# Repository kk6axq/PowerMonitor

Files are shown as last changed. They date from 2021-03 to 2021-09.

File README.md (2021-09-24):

# Power Monitor
This is a power management board for small robotics applications. This project was
developed as part of an honors contract for EGR216, electrical fundamentals,
during my Spring 2021 semester at Arizona State University, under the guidance
of Dr. Ayan Mallik.

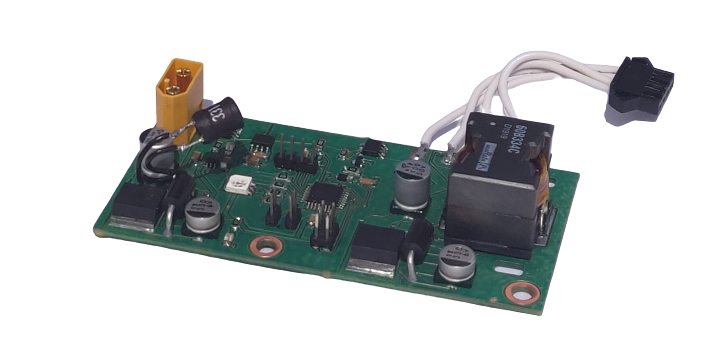
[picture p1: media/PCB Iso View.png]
PCB Photo


# Purpose
The purpose of this project was to interface with a LiPo battery for a robotics
project I am developing in another course. The purpose of the board was to
prevent issues stemming from over discharge of the battery or accidental shorting.
As LiPo batteries are capable of delivering a large amount of current,
I wanted to prevent circuit damage in the case of short circuit conditions while
also preventing battery damage if I forgot to turn off the robot.
Additionally, I wanted to explore an alternative to the LM7805 I had used in
previous projects to provide a high current 5V supply for a planned payload bay
on the robot.
# Features
* Variety of current protection features:
  * Overcurrent up to 10A
  * Overvoltage detection up to 25V
  * Undervoltage detection
  * Short circuit protection
* Independent load control. Load, and 5V load supply can be switched on or off by the onboard microcontroller.
* Provides 5V at up to 3A and 12V at up to 10A burst.
* Dual power supplies for load and onboard microcontroller.
* Serial based monitoring and control of load switch, power status, and fault conditions.
* Onboard RGB LED for status indication
* Open source software.
* Hardware schematic and layout is open source. Project files are currently not available due to licensing restrictions.
# Design Criteria
* 12V power source or 3s LiPo battery
* Provide 12V at 4.2A from battery and 5V at 1.5A
* Monitor for fault conditions, including overvoltage, undervoltage, overcurrent, and short circuit
* Report faults to the robot's main microcontroller

# Core components:
* ATTiny88 microcontroller programmed with Arduino and the ATTinyCore
* ACS722 Current Sensor with +/- 10A current measuring capacity
* Voltage divider based voltage sensor with 25V measuring capability
* Dual LM2576 5V buck converter
* MIC5504 3.3V regulator for current sensor
* Si4435 P-Channel MOSFET for short circuit protection and load switching
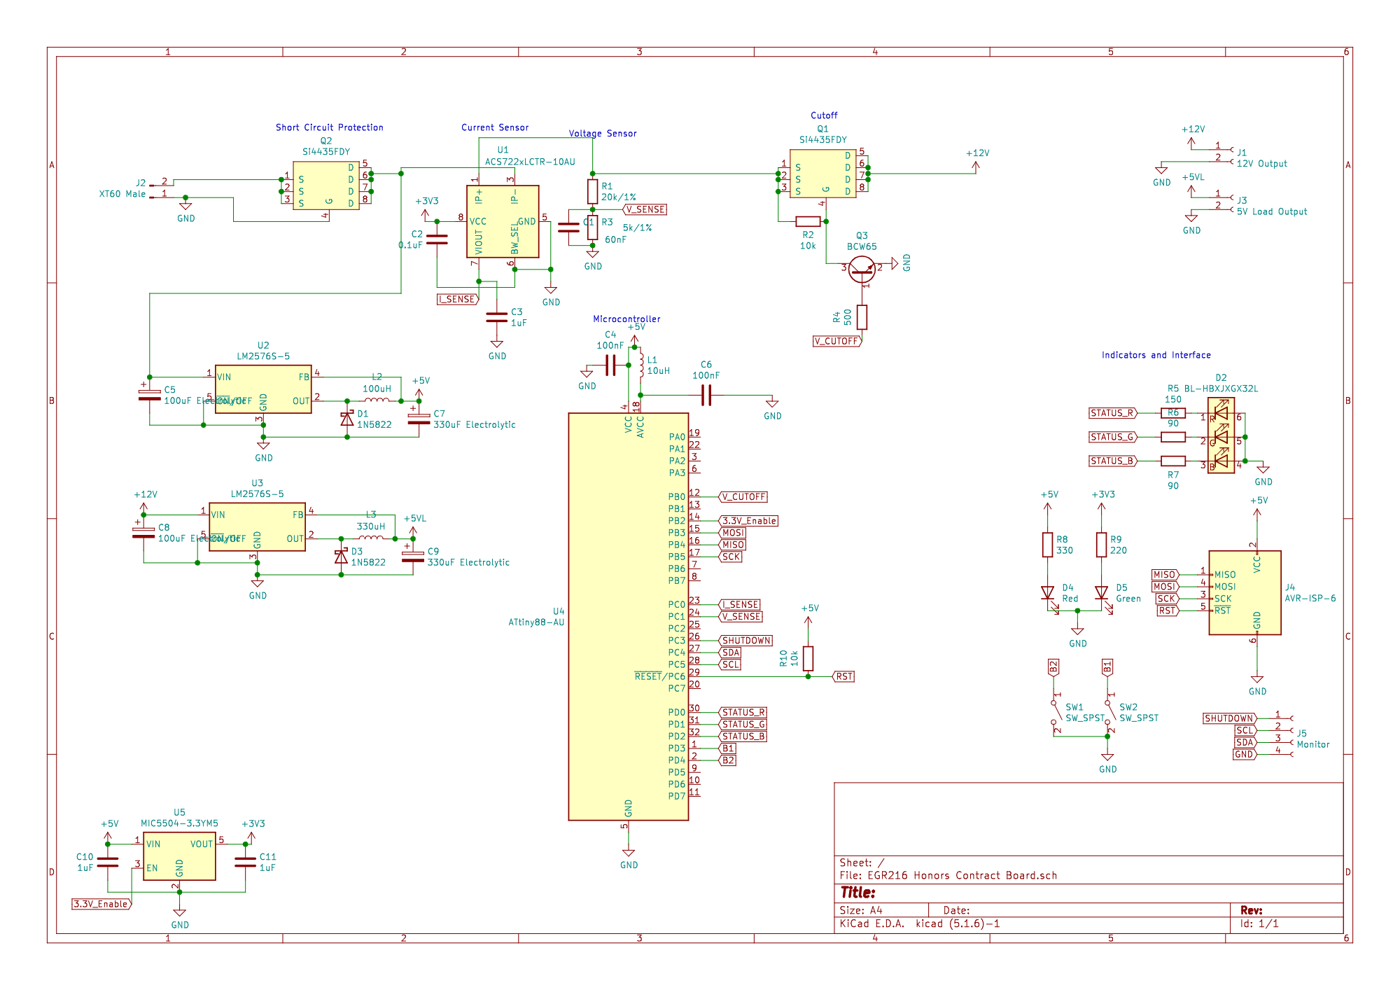
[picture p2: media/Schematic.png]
Schematic

# Repository Structure:
The repository is organized by folder, as shown below.
## Hardware
The hardware folder contains the KiCAD project files and output Gerbers and PDFs
for easy viewing. It includes:
* PDF schematic
* STEP file of PCB
* Bill of Materials
* Interactive HTML BOM for PCB assembly
* KiCAD project files
* Archive of Gerber board files and PDF of PCB layers

## Software
The software folder contains the code used to enable the power management behaviors.
## Docs
The docs folder contains documentation of the digital communications protocol and an explanation of the operation of the device.

# License
This project is copyright (C) 2021 by Lukas Severinghaus. It is licensed under the GNU GPLV3.

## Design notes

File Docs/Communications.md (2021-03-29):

# Digital Communications Protocol
The board communicates over a 9600 baud UART connection provided through the
onboard payload connector. The connector itself is a 4 pin 2.54mm pitch male
connector that can easily be interfaced with jumper wires or a 2.54mm pitch
wiring harness. This UART runs on a 5V logic level, though it should be capable
of receiving 3.3V logic level signals.

## Purpose
The purpose of the protocol is to provide an interface for the host device to
monitor the power status, and to provide human readable debugging output and
control.
## Protocol basics
There are two packet structures in the protocol. All packets start with either
`$` or `&` and end with a `;` character, all in ASCII. Packets starting with a
`&` are human readable debug messages, and are sent on major state changes.
Messages starting with `$` are human readable debug messages, and are currently
only sent on request. Commands can be sent to the device by sending a single
character.

## Commands
The following single character commands are recognized. All others, including
newline characters, are ignored.
* `m`: Enter command mode. The device will begin accepting
character commands/
* `x`: Exist command mode. The device will stop accepting character commands.
* `r`: Reset the current fault. Resets the state machine to the no fault state, though it may go immediately back into a fault state if the fault conditions persist.
* `d`: Print debug packet. Prints the debug response, detailed below.
* `o`: Turn on load. Sets the load cutoff switch to allow current to flow into the load.
* `l`: Turn off load. Sets the load cutoff switch to prevent current from flowing into the load.

## Debug response
The only machine readable response currently given is the debug command. This is
sent when the `d` character is sent to the device. The current response is in
the form:

  `$ Power_State Current Voltage Fault_State;`

`Power_State` is the current state of the load switch, `1` for load on,
and `0` for load off. `Current` is the measured load current in Amps. `Voltage`
is the measured supply voltage, in Volts. `Fault_State` is a flag for the current
state of the protection state machine. It has the following response codes:
* `c`: State clear. Everything is fine.
* `t`: An initial fault has been observed and the device is waiting to see if
the condition persists beyond the timeout limit.
* `s`: A soft trip fault has been encountered. The system has experienced a
recoverable fault and will periodically check to see if the fault has been
resolved. As of now the two soft trip conditions are overcurrent and overvoltage.
* `h`: A hard trip fault has been encountered. Ths system experienced an
unrecoverable fault and must be manually reset either by power cycling the
device or sending the `r` reset command. As of now, the only hard trip condition
is under voltage.
* `u`: Unknown condition. This should never be received in normal operation. If
it is, the device should be reset as there has been a fault in the code.

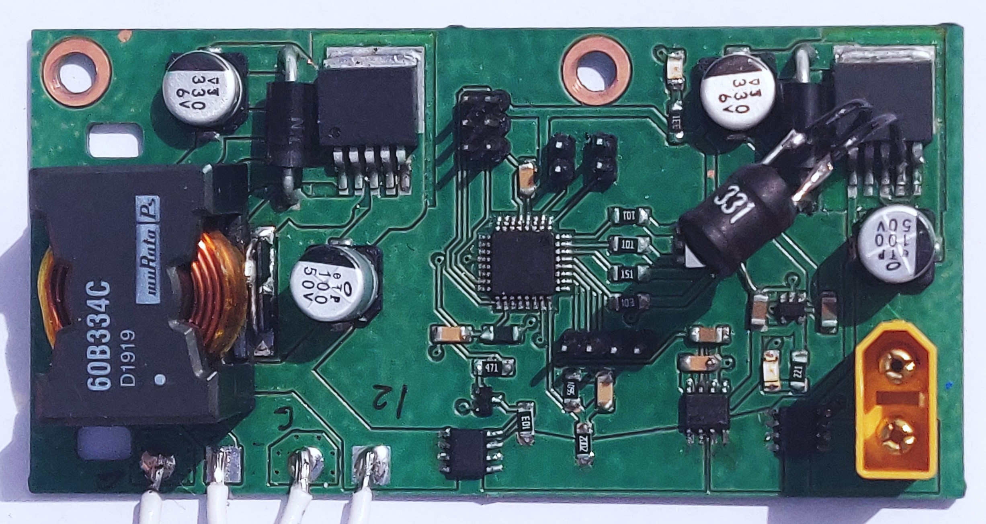
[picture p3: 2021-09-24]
media/PCB Front.jpg

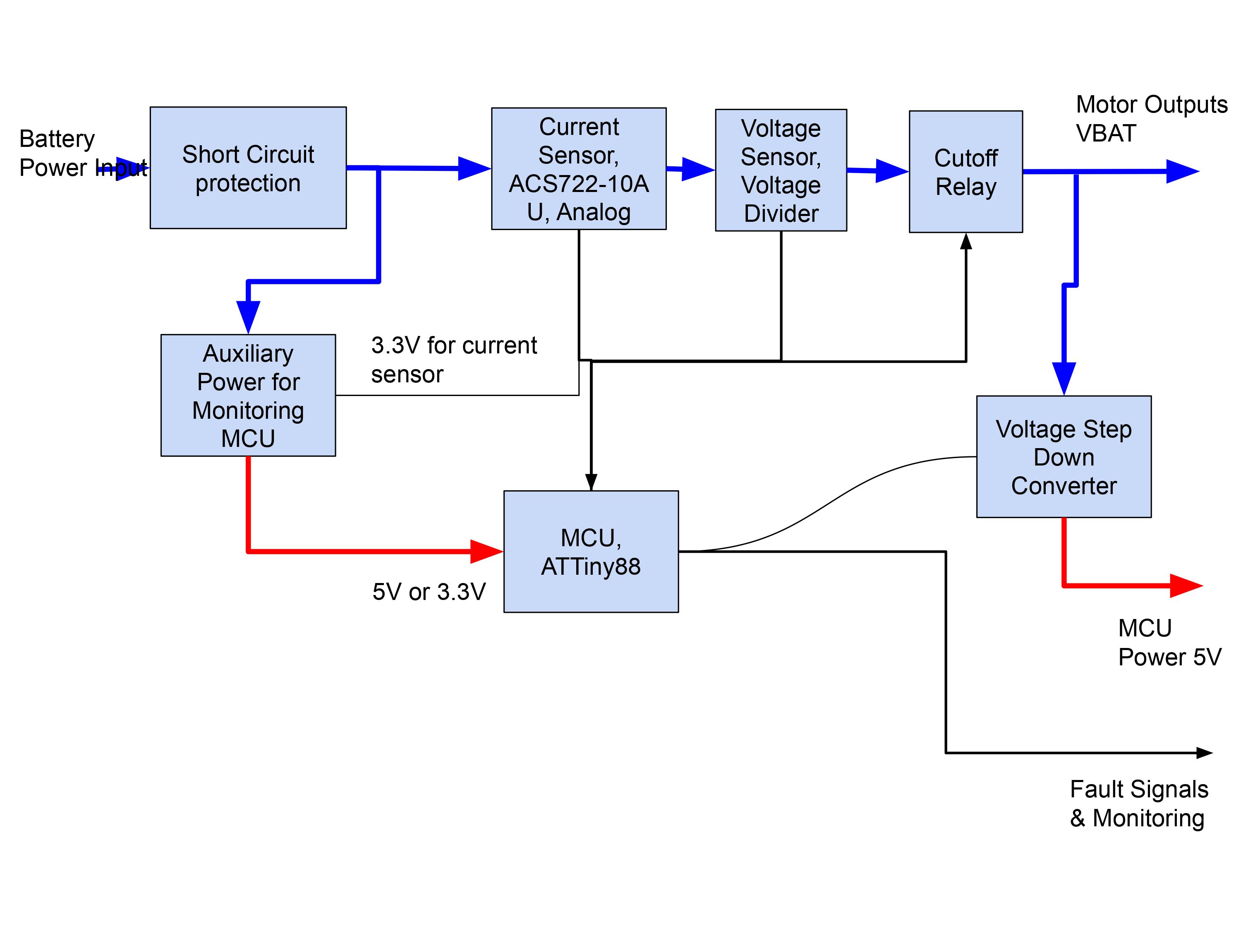
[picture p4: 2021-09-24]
media/Block Diagram.jpg

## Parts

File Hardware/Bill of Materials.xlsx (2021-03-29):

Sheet: Through Hole BOM
Universal Reference | Board Reference | Qty | Actual Qty | Value | Footprint | Part number | Price | Note |  | One board price |  | Total purchase price
Power THT C1 | C1 | 1 | 10 | 60nF | THT | 399-14063-ND | $0.26 |  |  | $0.26 |  | $2.59
Power THT C11 C10 C3 | C11 C10 C3 | 3 | 15 | 1uF | THT | 445-8395-ND | $0.22 |  |  | $0.66 |  | $3.30
Power THT C2 | C2 | 1 | 10 | 0.1uF | THT | 399-4151-ND | $0.16 |  |  | $0.16 |  | $1.57
Power THT C5 C8 | C5 C8 | 2 | 10 | 100uF Electrolytic | THT | 1572-1659-ND | $0.13 |  |  | $0.25 |  | $1.26
Power THT C6 C4 | C6 C4 | 2 | 10 | 100nF | THT | 399-4151-ND | $0.16 |  |  | $0.31 |  | $1.57
Power THT C7 C9 | C7 C9 | 2 | 10 | 330uF Electrolytic | THT | 1572-1437-ND | $0.21 |  |  | $0.43 |  | $2.15
Power THT D1 D3 | D1 D3 | 2 |  | 1N5822 | THT | 497-11370-1-ND | $0.28 |  |  | $0.56 |  | $0.00
Power THT D2 | D2 | 1 | 1 | BL-HBXJXGX32L | 5050 | BL-HBXJXGX32LCT-ND | $0.40 | Use SMD |  | $0.40 |  | $0.40
Power THT D4 | D4 | 1 | 10 |  |  |  |  | Already Have |  | $0.00 |  | $0.00
Power THT D5 | D5 | 1 | 10 |  |  |  |  | Already Have |  | $0.00 |  | $0.00
Power THT J1 | J1 | 1 |  | 12V Output |  |  |  | Already Have |  | $0.00 |  | $0.00
Power THT J2 | J2 | 1 |  | XT60 Male | Amass:AMASS_XT60-M_1x02_P7.20mm_Vertical |  |  | Already Have |  | $0.00 |  | $0.00
Power THT J3 | J3 | 1 |  | 5V Load Output | Connector_PinHeader_2.54mm:PinHeader_1x02_P2.54mm_Vertical |  |  | Already Have |  | $0.00 |  | $0.00
Power THT J4 | J4 | 1 | 5 | AVR-ISP-6 | 2x3 2.54 |  |  | Already Have |  | $0.00 |  | $0.00
Power THT J5 | J5 | 1 |  | Monitor | 2.54 |  |  | Already Have |  | $0.00 |  | $0.00
Power THT L1 | L1 | 1 | 5 | 10uH | THT | 78F100J-TR-RCTR-ND | $0.25 |  |  | $0.25 |  | $1.26
Power THT L2 L3 | L2 L3 | 2 | 3 | 330uH | THT | 595-1734-ND | $2.54 |  |  | $5.08 |  | $7.62
Power THT Q2 Q1 | Q2 Q1 | 2 | 10 | Si4435FDY | SOIC8 | SI4435FDY-T1-GE3CT-ND | $0.38 | Use SMD |  | $0.76 |  | $3.82
Power THT Q3 | Q3 | 1 | 10 | BC856 | SOT23-3 | BC856BLT3GOSCT-ND | $0.09 | Use SMD |  | $0.09 |  | $0.88
Power THT R1 | R1 | 1 | 5 | 20k/1% | THT | RNF14FTD20K0TR-ND | $0.10 |  |  | $0.10 |  | $0.50
Power THT R10 R2 | R10 R2 | 2 | 20 | 10k |  |  |  | Already have |  | $0.00 |  | $0.00
Power THT R3 | R3 | 1 | 5 | 5k/1% | THT | 1135-1619-ND | $0.50 |  |  | $0.50 |  | $2.50
Power THT R4 | R4 | 1 | 10 | 500 | THT | CF14JT470RCT-ND | $0.04 | 470ohms |  | $0.04 |  | $0.36
Power THT R5 | R5 | 1 | 10 | 150 | THT | CF14JT150RCT-ND | $0.04 |  |  | $0.04 |  | $0.36
Power THT R6 R7 | R6 R7 | 2 | 10 | 90 | THT | CF14JT100RCT-ND | $0.04 | 100ohms |  | $0.07 |  | $0.36
Power THT R8 | R8 | 1 | 10 | 330 |  |  |  | Already Have |  | $0.00 |  | $0.00
Power THT R9 | R9 | 1 | 10 | 220 |  |  |  | Already Have |  | $0.00 |  | $0.00
Power THT SW2 SW1 | SW2 SW1 | 2 | 2 | SW_SPST |  |  |  | Already Have |  | $0.00 |  | $0.00
Power THT U1 | U1 | 1 | 1 | ACS722xLCTR-10AU | SOIC8 | 620-1636-1-ND | $3.94 | Use SMD |  | $3.94 |  | $3.94
Power THT U2 U3 | U2 U3 | 2 | 3 | LM2576S-5 | THT | 576-1518-5-ND | $2.01 |  |  | $4.02 |  | $6.03
Power THT U4 | U4 | 1 | 5 | ATtiny88-AU | THT | ATTINY88-PU-ND | $1.80 |  |  | $1.80 |  | $9.00
Power THT U5 | U5 | 1 | 10 | MIC5504-3.3YM5 | SOT-23-5 | 576-4764-1-ND | $0.13 | Use SMD |  | $0.13 |  | $1.30
 |  |  |  |  |  |  |  |  | Total | $19.85 | Total | $50.77

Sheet: SMD BOM
Universal Reference | Board Reference | Qty | Actual Qty | Value | Footprint | Part number | Price | Note |  | One board price |  | Actual price | Status: | Ready to order
Power C1 | C1 | 1 | 10 | 60nF | 1206 | 2368-SMC1206K563-ND | $0.12 |  |  | $0.12 |  | $1.24
Power C11 C10 C3 | C11 C10 C3 | 3 | 15 | 1uF | 1206 | 1276-1097-2-ND | $0.10 |  |  | $0.31 |  | $1.53
Power C2 | C2 | 1 |  | 0.1uF | 1206 | 2368-SMC1206Z104-ND | $0.05 |  |  | $0.05 |  | $0.00
Power C5 C8 | C5 C8 | 2 | 10 | 100uF Electrolytic | Axial | 2616-VUJ101M1HTR-1313STR-ND | $0.12 |  |  | $0.24 |  | $1.20
Power C6 C4 | C6 C4 | 2 | 10 | 100nF | 1206 | 2368-SMC1206Z104-ND | $0.05 |  |  | $0.10 |  | $0.48
Power C7 C9 | C7 C9 | 2 | 10 | 330uF Electrolytic | Axial | 493-2091-2-ND | $0.22 |  |  | $0.44 |  | $2.21
Power D1 D3 | D1 D3 | 2 |  | 1N5822 | Axial | 497-11370-1-ND | $0.28 |  |  | $0.56 |  | $0.00
Power D2 | D2 | 1 | 10 | BL-HBXJXGX32L | 5050 | BL-HBXJXGX32LCT-ND | $0.40 |  |  | $0.40 |  | $4.01
Power D4 | D4 | 1 | 10 | RED | 1206 | 160-1168-1-ND | $0.18 | Vf 2v |  | $0.18 |  | $1.76
Power D5 | D5 | 1 | 10 | GREEN | 1206 | 160-1169-2-ND | $0.17 | Vf 2.1v |  | $0.17 |  | $1.69
Power J1 | J1 | 1 |  | 12V Output |  |  |  | Already Have |  | $0.00 |  | $0.00
Power J2 | J2 | 1 |  | XT60 Male | Amass:AMASS_XT60-M_1x02_P7.20mm_Vertical |  |  | Already Have |  | $0.00 |  | $0.00
Power J3 | J3 | 1 |  | 5V Load Output | Connector_PinHeader_2.54mm:PinHeader_1x02_P2.54mm_Vertical |  |  | Already Have |  | $0.00 |  | $0.00
Power J4 | J4 | 1 | 5 | AVR-ISP-6 | 2x3 2.54 | 2057-PH2-06-UA-ND | $0.12 |  |  | $0.12 |  | $0.60
Power J5 | J5 | 1 |  | Monitor | Connector_PinHeader_2.54mm:PinHeader_1x04_P2.54mm_Vertical |  |  | Already Have |  | $0.00 |  | $0.00
Power L1 | L1 | 1 | 5 | 10uH | 1206 | 541-2607-2-ND | $0.23 | 25mA max |  | $0.23 |  | $1.15
Power L2 L3 | L2 L3 | 2 | 3 | 330uH | nonstandard | 811-2464-ND | $2.97 |  |  | $5.94 |  | $8.91
Power Q2 Q1 | Q2 Q1 | 2 | 10 | Si4435FDY | SOIC8 | SI4435FDY-T1-GE3CT-ND | $0.38 |  |  | $0.76 |  | $3.82
Power Q3 | Q3 | 1 | 10 | BC856 | SOT23-3 | BC856BLT3GOSCT-ND | $0.09 |  |  | $0.44 |  | $2.21
Power R1 | R1 | 1 | 10 | 20k/1% | 1206 | 311-20.0KFRCT-ND | $0.10 |  |  | $0.56 |  | $0.00
Power R10 R2 | R10 R2 | 2 | 20 | 10k | 1206 | RMCF1206JT10K0CT-ND | $0.03 | Already have |  | $0.40 |  | $4.01
Power R3 | R3 | 1 | 10 | 5k/1% | 1206 | A129819CT-ND | $0.10 |  |  | $0.18 |  | $1.76
Power R4 | R4 | 1 | 10 | 500 | 1206 | RMCF1206JT470RCT-ND | $0.03 | 470ohms |  | $0.17 |  | $1.69
Power R5 | R5 | 1 | 10 | 150 | 1206 | RMCF1206JT150RCT-ND | $0.03 |  |  | $0.00 |  | $0.00
Power R6 R7 | R6 R7 | 2 | 10 | 90 | 1206 | RMCF1206JT100RCT-ND | $0.03 | 100ohms |  | $0.00 |  | $0.00
Power R8 | R8 | 1 | 10 | 330 | 1206 | RMCF1206JT330RCT-ND | $0.03 |  |  | $0.00 |  | $0.00
Power R9 | R9 | 1 | 10 | 220 | 1206 | RMCF1206JT220RCT-ND | $0.03 |  |  | $0.12 |  | $0.60
Power SW2 SW1 | SW2 SW1 | 2 |  | SW_SPST |  |  |  | Already Have |  | $0.00 |  | $0.00
Power U1 | U1 | 1 | 5 | ACS722xLCTR-10AU | SOIC8 | 620-1636-1-ND | $3.94 |  |  | $0.23 |  | $1.15
Power U2 U3 | U2 U3 | 2 | 6 | LM2576S-5 | TO265-5 | LM2576S-5.0/NOPB-ND | $3.53 |  |  | $5.94 |  | $8.91
Power U4 | U4 | 1 | 5 | ATtiny88-AU | TQFP32 | ATTINY88-AU-ND | $1.04 |  |  | $0.76 |  | $3.82
Power U5 | U5 | 1 | 10 | MIC5504-3.3YM5 | SOT-23-5 | 576-4764-1-ND | $0.13 |  |  | $0.09 |  | $0.88
 |  |  |  |  |  |  |  |  | Total: | $18.51 | Total: | $53.63

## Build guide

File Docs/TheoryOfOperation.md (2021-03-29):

# Theory of Operation
The device functions on a fairly basic state machine. There are currently 3 fault conditions that are measured: overcurrent, undervoltage, and overvoltage.

For each of these, the applicable sensor is measured against a
threshold value and a corresponding flag is set. If the system
is currently in a clear state, meaning there are no existing faults, the system transitions into a time state, where it checks if the faults persist for more than the timeout threshold, 50ms. If the fault condition still persists, it decides, based on the type of fault, whether to enter a soft or hard fault.

A soft fault is a condition that is likely momentary, and can be recovered from. The two situations envisioned are momentary overcurrent spikes from the motors stalling or a brief high voltage spike from back EMF from the motors. In this case, the system disconnects the load but will reconnect it once per second to see if the condition has been resolved. Once it has, the system returns to the normal clear state.

A hard fault is a condition that is likely permanent, and needs human intervention to be resolved. The situation envisioned for this is a low voltage condition, where the battery needs to be replaced to prevent damage from undervoltage. In this case, the system disconnects the load and will wait for either a system reset, as in the case of a battery replacement, or a reset command from the host microcontroller. If neither of these are met, the system will perpetually stay in a load-disconnected hard fault state, otherwise, once the flag is reset by one of those two methods, the system will return to a normal fault clear state.

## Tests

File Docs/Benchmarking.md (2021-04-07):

# Benchmarking
To verify the functionality of the device, I performed static load testing using high wattage resistors to check voltage ripple under load. These tests were performed in Dr. Mallik's lab on April 7, 2021.

## 5V system
The 5V on board switching regulator was tested at three load conditions: no load, 1A load, and 2A load. The raw results of the test are shown below:

### Raw Testing Data
| Trial | Unit | 1 | 2 | 3 |
|---|---|---|---|---|
| Current | A | 0 | 1 | 2 |
| Expected V | V | 5 | 5 | 5 |
| RMS | Vrms | 4.85  | 4.796 | 4.795 |
| Max | V | 4.95  | 4.91  | 4.905 |
| Min | V | 4.78  | 4.71  | 4.7 |
| P-P Ripple | mV | 150 | 220 | 207 |
| Load | Ohm  | 0 | 5 | 2.5 |
| Ripple | % | 3.09% | 4.59% | 4.32% |

### Graphed Ripple
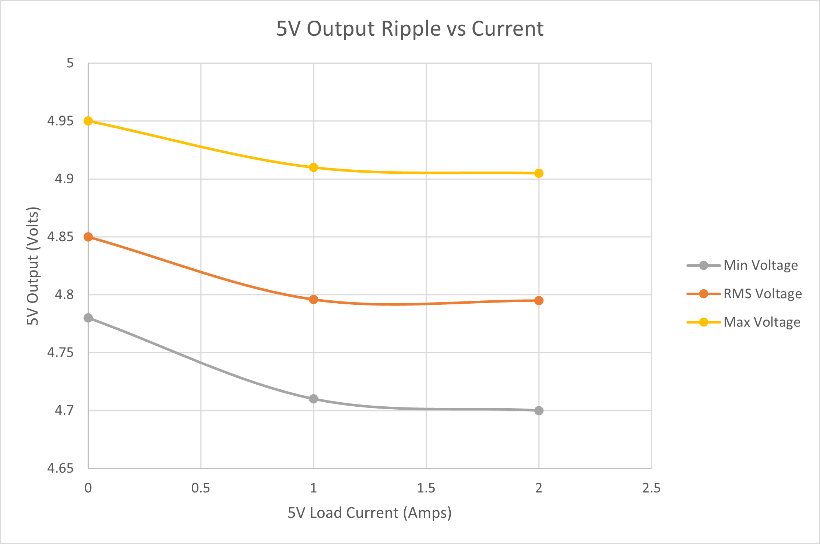
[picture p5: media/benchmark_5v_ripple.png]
Graphed voltage ripple


This data shows that the switching regulator can supply a sufficient voltage, even at high current. The circuitry is rated for 3A, so even at 83% load (2.5A) it stayed within about 200mV of 5V.

## 12V system
The 12V output is a direct feed from the input supply, it only passes through the reverse current protection and power cutoff MOSFETs before being output. I was unable to measure the input ripple at the same time as the output ripple, so it is difficult to draw conclusions on the power handling capability of the board, or any voltage drop therein, but this testing verified that, at a minimum, the board can handle 4.8A for brief periods of time without damage.

### Raw Testing Data
| Trial | | 1 | 2 | 3 |
|---|---|---|---|---|
| Current | A | 0 | 2.4 | 4.8 |
| Expected V | V | 12 | 12 | 12 |
| RMS | Vrms | 11.81 | 11.48 | 11.24 |
| Max | V | 11.91 | 11.57 | 11.33 |
| Min | V | 11.71 | 11.38 | 11.12 |
| P-P Ripple | mV | 190 | 183.7 | 205.9 |
| Load | Ohm  | 0 | 5 | 2.5 |
| Ripple % | % | 1.61% | 1.60% | 1.83% |

### Graphed Ripple
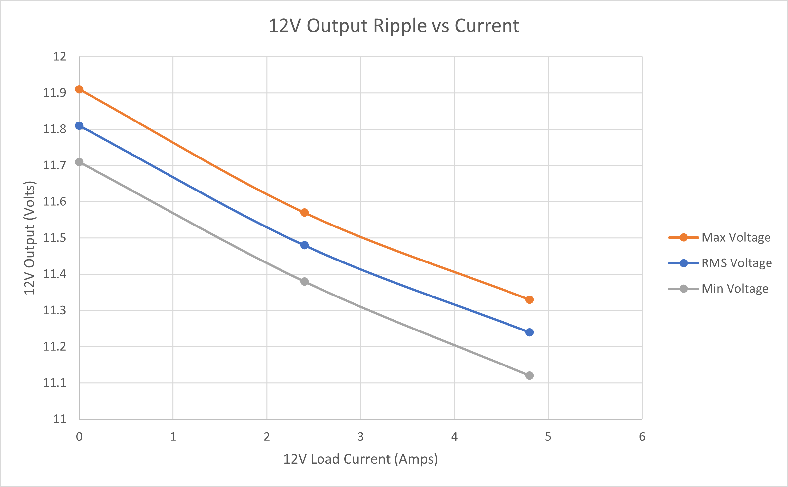
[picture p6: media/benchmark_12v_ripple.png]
Graphed voltage ripple


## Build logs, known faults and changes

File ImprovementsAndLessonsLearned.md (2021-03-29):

# Future Improvements and Lessons Learned
I embarked on this project to help gain a better understanding of another part of the robotics ecosystem, and how power electronics play a part in a robotic system. As such, I will likely be using, and improving, on this design in the future, and below is a list of improvements and lessons learned from the semester's development cycle:
## Lessons learned
* **Get a professionally produced PCB.** Most of the PCB debugging issues were due to the production of the PCB, which I got produced at an on campus PCB mill. Milling a PCB does not normally remove all the excess copper, unlike the methods used in commercial board houses, and uses a less reliable solder mask. This can, and in this project did, lead to shorting, and component damage from traces connecting to the edges of the excess copper where the solder mask was not fully adhered. In these high current applications, it is worth the extra price to get a commercially produced PCB to not have to debug tiny trace issues.
* **Add more test points.** I didn't add any test points on this PCB, and I had to probe many of the pins on the SMD packages directly, leaving the potential for shorting leads together. For future projects, I would incorporate a series of small test points where the risk of shorts would be lower.
* **Run the DRC checks before production.** This was a rookie mistake, but I forgot to run the DRC checks in KiCAD before getting the PCB milled, leading to one trace being left unconnected.
## Improvements
* **Find a replacement for the LM2576 and its large inductor.** The inductor for the LM2576 is a 330uH 3A device that is almost a 1in (25mm) cube. I didn't realize this until I received the components, so next time I would investigate a smaller inductance switching regulator to reduce the physical footprint. Additionally, high current inductors are rather expensive, so this would help reduce the project cost.
* **Substitute a smaller buck converter for the onboard 5V supply.** To simplify the design, I duplicated the load buck converter for the onboard 5V supply, using mostly the same 3A rated components for a ~50mA load. For the next version, I would replace this with a smaller version, even an LM7805 with a thermal footprint would likely work in the application.
* **Add a 5V jumper on the ICSP header.** To prevent damage to my computer, I isolated the 5V rail on the device from the 5V line on my programmer. Although the programmer has its own power jumper, for the next version it would be prudent to add a jumper to disconnect the 5V rail from the 5V pin on the ICSP header.

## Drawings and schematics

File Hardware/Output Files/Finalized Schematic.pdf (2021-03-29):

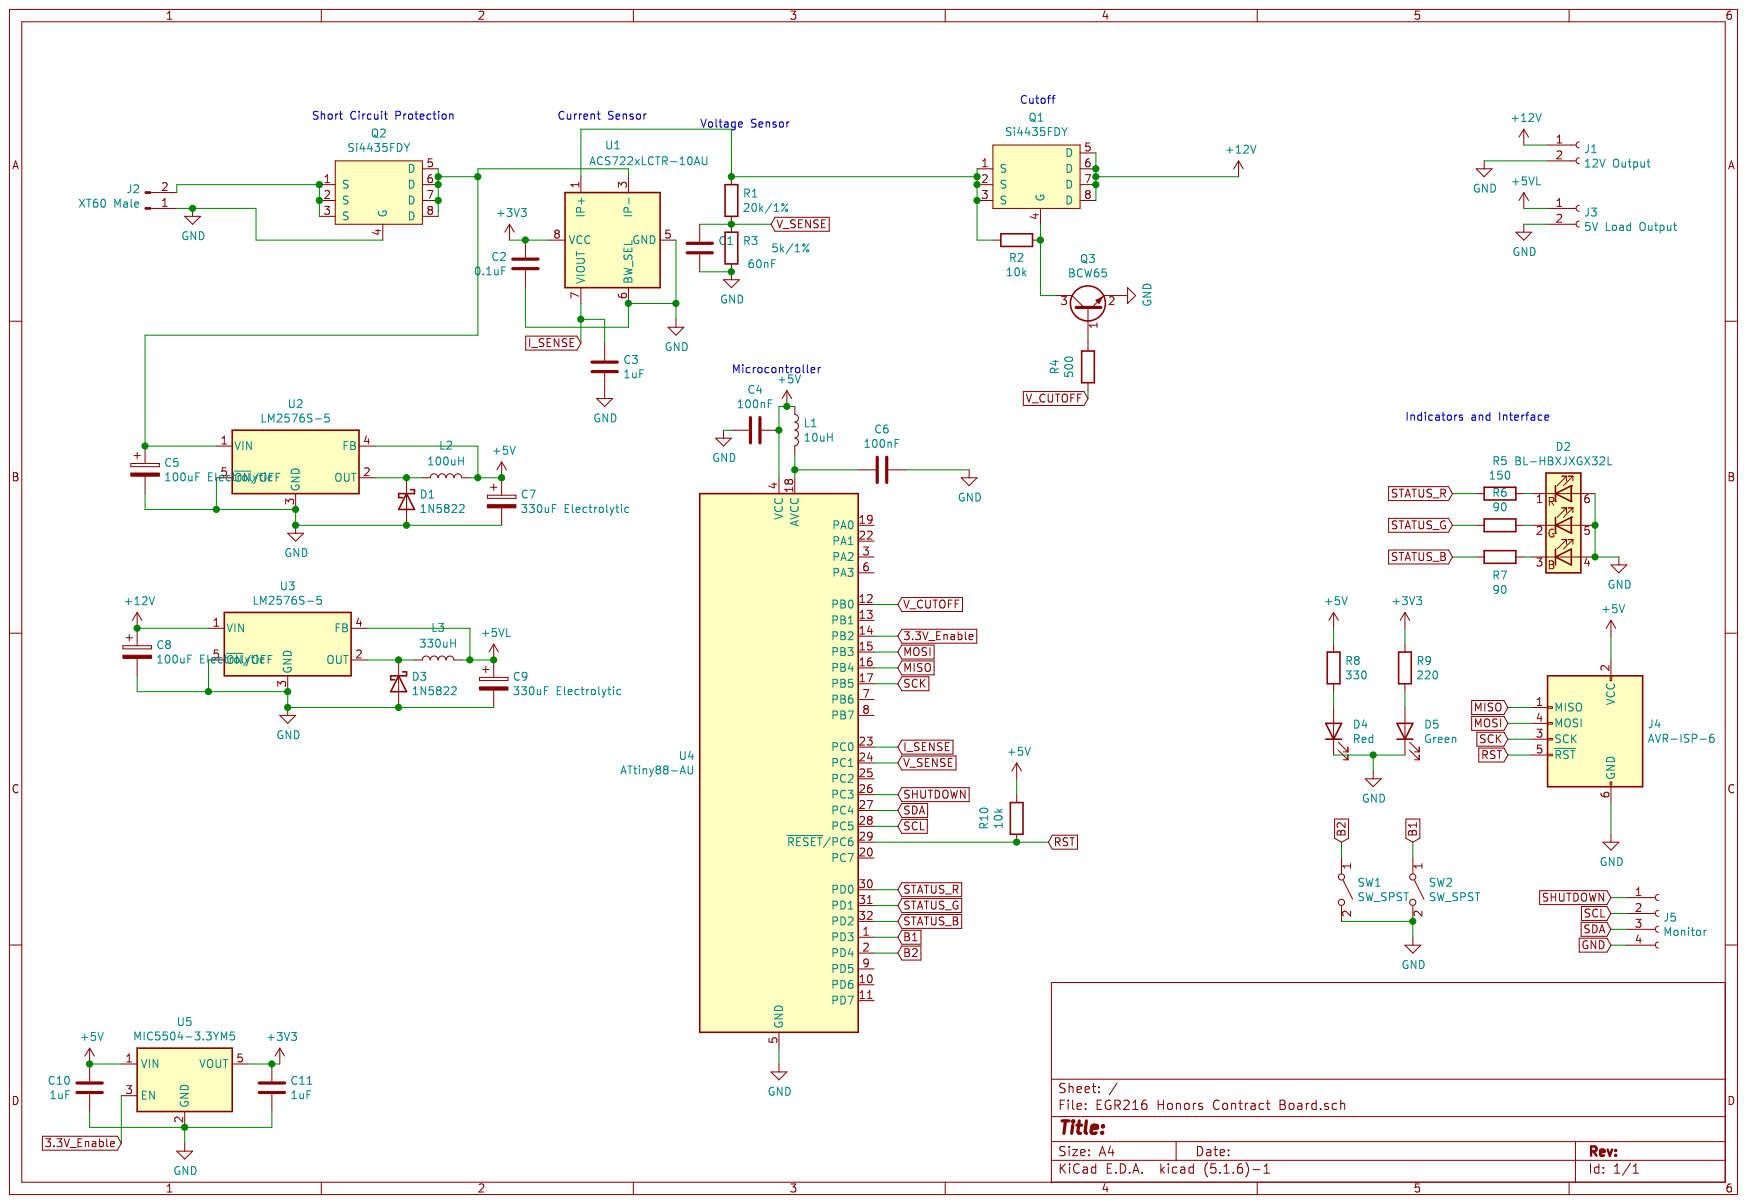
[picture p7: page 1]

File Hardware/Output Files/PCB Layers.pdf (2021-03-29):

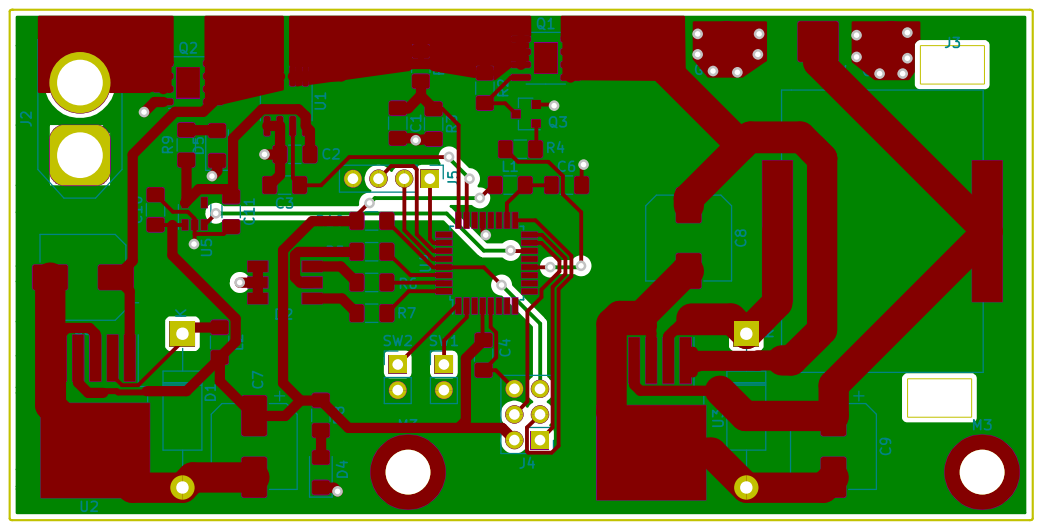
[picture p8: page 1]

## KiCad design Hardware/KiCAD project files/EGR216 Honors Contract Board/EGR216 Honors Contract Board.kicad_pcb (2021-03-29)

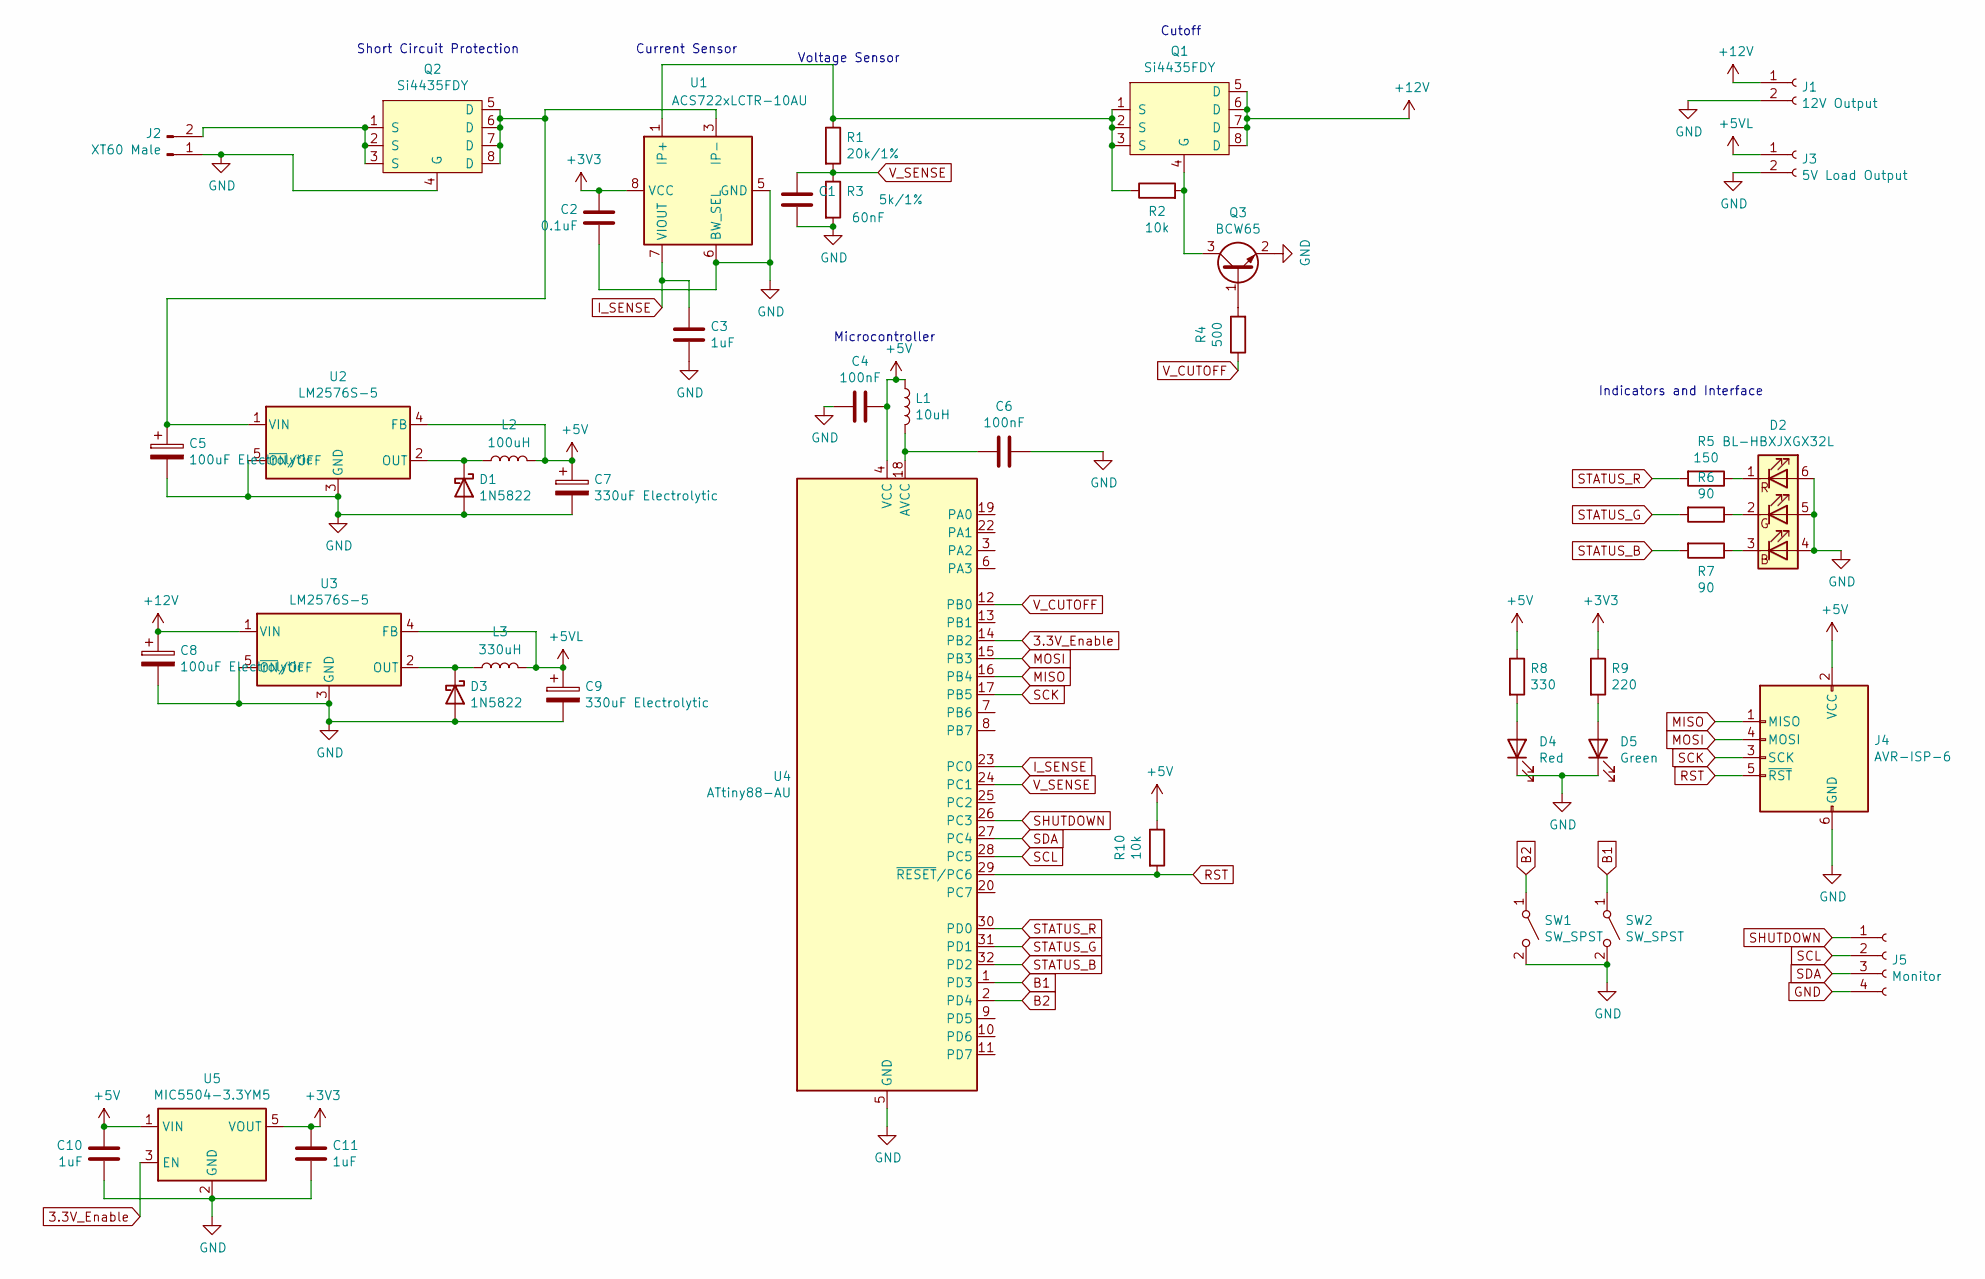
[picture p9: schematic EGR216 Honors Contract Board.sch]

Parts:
C1: 60nF; C_1206_3216Metric_Pad1.42x1.75mm_HandSolder
C2: 0.1uF; C_1206_3216Metric_Pad1.42x1.75mm_HandSolder
C3, C10, C11: 1uF; C_1206_3216Metric_Pad1.42x1.75mm_HandSolder
C4, C6: 100nF; C_1206_3216Metric_Pad1.42x1.75mm_HandSolder
C5, C8: 100uF Electrolytic; CP_Elec_8x10
C7, C9: 330uF Electrolytic; CP_Elec_8x5.4
D1, D3: 1N5822; D_DO-15_P15.24mm_Horizontal
D2: BL-HBXJXGX32L
D4: Red; LED_1206_3216Metric_Pad1.42x1.75mm_HandSolder
D5: Green; LED_1206_3216Metric_Pad1.42x1.75mm_HandSolder
J1: 12V Output; SolderWire-2.5sqmm_1x02_P7.2mm_D2.4mm_OD3.6mm_SMD
J2: XT60 Male; AMASS_XT60-M_1x02_P7.20mm_Vertical
J3: 5V Load Output; SolderWire-2.5sqmm_1x02_P7.2mm_D2.4mm_OD3.6mm_SMD
J4: AVR-ISP-6; PinHeader_2x03_P2.54mm_Vertical
J5: Monitor; PinHeader_1x04_P2.54mm_Vertical
L1: 10uH; L_1206_3216Metric_Pad1.42x1.75mm_HandSolder
L2: 100uH; L_1206_3216Metric_Pad1.42x1.75mm_HandSolder
L3: 330uH; Inductor-Murata-6000B
Q1, Q2: Si4435FDY; SOIC-8-1EP_3.9x4.9mm_P1.27mm_EP2.29x3mm
Q3: BCW65; SOT-23
R1: 20k/1%; R_1206_3216Metric_Pad1.42x1.75mm_HandSolder
R2, R10: 10k; R_1206_3216Metric_Pad1.42x1.75mm_HandSolder
R3: 5k/1%; R_1206_3216Metric_Pad1.42x1.75mm_HandSolder
R4: 500; R_1206_3216Metric_Pad1.42x1.75mm_HandSolder
R5: 150; R_1206_3216Metric_Pad1.42x1.75mm_HandSolder
R6, R7: 90; R_1206_3216Metric_Pad1.42x1.75mm_HandSolder
R8: 330; R_1206_3216Metric_Pad1.42x1.75mm_HandSolder
R9: 220; R_1206_3216Metric_Pad1.42x1.75mm_HandSolder
SW1, SW2: SW_SPST; PinHeader_1x02_P2.54mm_Vertical
U1: ACS722xLCTR-10AU; SOIC-8_3.9x4.9mm_P1.27mm
U2, U3: LM2576S-5; TO-263-5_TabPin3
U4: ATtiny88-AU; TQFP-32_7x7mm_P0.8mm
U5: MIC5504-3.3YM5; SOT-23-5

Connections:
3.3V_Enable: U4.14 (PB2), U5.3 (EN)
+3V3: C2.1, C11.1, R9.1, U1.8 (VCC), U5.5 (VOUT)
+5V: C4.2, C7.1, C10.1, J4.2 (VCC), L1.1, L2.2, R8.1, R10.1, U2.4 (FB), U4.4 (VCC), U5.1 (VIN)
+5VL: C9.1, J3.1, L3.2, U3.4 (FB)
+12V: C8.1, J1.1, Q1.5 (D), Q1.6 (D), Q1.7 (D), Q1.8 (D), U3.1 (VIN)
B1: SW2.1 (A), U4.1 (PD3)
B2: SW1.1 (A), U4.2 (PD4)
I_SENSE: C3.1, U1.7 (VIOUT), U4.23 (PC0)
MISO: J4.1 (MISO), U4.16 (PB4)
MOSI: J4.4 (MOSI), U4.15 (PB3)
unnamed: C5.1, Q2.5 (D), Q2.6 (D), Q2.7 (D), Q2.8 (D), U1.3 (IP-), U1.4 (IP-), U2.1 (VIN)
unnamed: C6.1, L1.2, U4.18 (AVCC)
unnamed: D1.1 (K), L2.1, U2.2 (OUT)
unnamed: D2.1 (RK), R5.1
unnamed: D2.2 (GK), R6.1
unnamed: D2.3 (BK), R7.1
unnamed: D3.1 (K), L3.1, U3.2 (OUT)
unnamed: D4.2 (A), R8.2
unnamed: D5.2 (A), R9.2
unnamed: J2.2, Q2.1 (S), Q2.2 (S), Q2.3 (S)
unnamed: Q1.1 (S), Q1.2 (S), Q1.3 (S), R1.1, R2.1, U1.1 (IP+), U1.2 (IP+)
unnamed: Q1.4 (G), Q3.3 (C), R2.2
unnamed: Q3.1 (B), R4.2
RST: J4.5 (~RST), R10.2, U4.29 (~RESET~/PC6)
SCK: J4.3 (SCK), U4.17 (PB5)
SCL: J5.2, U4.28 (PC5)
SDA: J5.3, U4.27 (PC4)
SHUTDOWN: J5.1, U4.26 (PC3)
STATUS_B: R7.2, U4.32 (PD2)
STATUS_G: R6.2, U4.31 (PD1)
STATUS_R: R5.2, U4.30 (PD0)
V_CUTOFF: R4.1, U4.12 (PB0)
V_SENSE: C1.1, R1.2, R3.1, U4.24 (PC1)

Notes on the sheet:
Short Circuit Protection
Current Sensor
Voltage Sensor
Microcontroller
Indicators and Interface
Cutoff

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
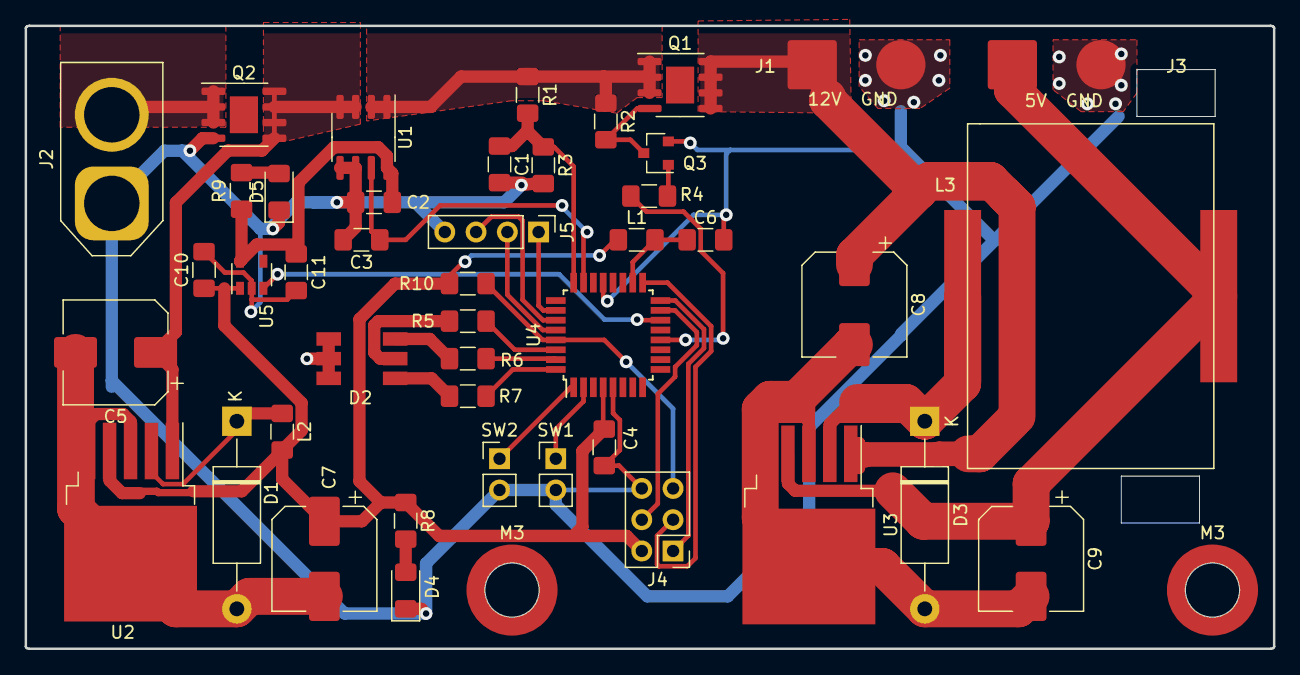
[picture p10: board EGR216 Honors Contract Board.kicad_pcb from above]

Board: 2 copper layers, 101.4 x 50.6 mm, 46 parts (0 on the bottom side), 35 nets.

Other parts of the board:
M3, M3#2: Mounting_Wuerth_WA-SMSI-M3_H2mm_9774020360

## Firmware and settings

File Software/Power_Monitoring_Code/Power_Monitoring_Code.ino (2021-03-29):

/**
 * File: Power_Monitoring_Code.ino
 * Author: Lukas Severinghaus
 * Date: March 28, 2021
 * Purpose: Enable power management and monitoring features
 * for my EGR216 honors contract project PCB.
 *
 * License:
 * Copyright (C) 2021 Lukas Severinghaus
 * This program is free software; you can redistribute it and/or
 * modify it under the terms of the GNU General Public License version 3
 * as published by the Free Software Foundation;
 * This program is distributed in the hope that it will be useful,
 * but WITHOUT ANY WARRANTY; without even the implied warranty of
 * MERCHANTABILITY or FITNESS FOR A PARTICULAR PURPOSE.  See the
 * GNU General Public License for more details.
 * You should have received a copy of the GNU General Public License
 * along with this program; if not, write to the Free Software
 * Foundation, Inc., 51 Franklin Street, Fifth Floor, Boston, MA  02110-1301, USA.
 */

#include <SoftwareSerial.h>

SoftwareSerial debug(21, 22); //Rx, Tx
#define DEBUG_BAUD 9600
/**** Fault Conditions ****/
#define OVERCURRENT_LIMIT 9.0

#define OVERVOLTAGE_LIMIT 14
#define UNDERVOLTAGE_LIMIT 10
/**** End Fault Conditions ****/

/**** LED Pins ****/
#define LED_R 0
#define LED_G 2
#define LED_B 1
/**** End LED Pins ****/

/**** Cutoff Relay Variables ****/
#define CUTOFF_PIN 8
//Pin state when circuit is open
#define CUTOFF_ENABLE LOW
//Pin state when circuit is closed
#define CUTOFF_DISABLE HIGH
//Current state of the cutoff
bool powerState = false;
/**** End Cutoff Relay Variables ****/

/**** Current Sensing Variables ****/

//TODO: Implement switching of 3.3v power supply after start.
//Controls whether the 3.3v regulator is enabled only when needed.
//This could reduce power usage, but could introduce additional wait times and possible voltage instability.
//#define SUPPLY_3V3_CONTROL
#undef SUPPLY_3V3_CONTROL

//Pin to control 3.3V regulator
#define SUPPLY_3V3_ENABLE_PIN 10
//Control states for 3.3V regulator
#define SUPPLY_3V3_ON HIGH
#define SUPPLY_3V3_OFF LOW

//Pin for current analog input
#define CURRENT_ADC_PIN A0

//Offset, in ADC steps, of the current sensor. Typical is 1.6V,~327 steps
int current_offset = 0;

//Filter strength of the LPF used on the raw current data
#define CURRENT_FILTER_STRENGTH 0.05

//Sensor output voltage is proportional to current
//This is the voltage change per amp of power, in millivolts
#define CURRENT_MV_PER_AMP -132
//ADC steps to volts
#define CURRENT_ADC_TO_VOLTS 5.0 / 1024.0
//ADC steps to amps
#define CURRENT_ADC_TO_AMPS CURRENT_ADC_TO_VOLTS * CURRENT_MV_PER_AMP / 1000.0
/**** End Current Sensing Variables ****/

/**** Voltage Sensing Variables ****/
//Pin for voltage analog input
#define VOLTAGE_ADC_PIN A1
//Voltage range of ADC. Voltage corresponding to a 1023 ADC reading
#define VOLTAGE_ADC_RANGE 22.857

#define VOLTAGE_FILTER_STRENGTH 0.05
/**** End Voltage Sensing Variables ****/

/**** Fault Control ****/
//Max time to stay in fault condition before disconnecting load, in ms.
#define FAULT_TIME_THRESHOLD 50

//Threshold values for voltage and current, in volts and amps respectively.
//Staying above these values for more than the time threshold will cause the load to be disconnected.
#define FAULT_MAX_CURRENT 1 //Max current
#define FAULT_MAX_VOLTAGE 15 //Fully charged voltage is ~12.3v
#define FAULT_MIN_VOLTAGE 10.5 //3.5V / cell with a 3s LiPo

//Millis time that last fault started
long fault_start_time = 0;

//Time to wait before attempting to clear soft trip, in ms
#define FAULT_SOFT_TRIP_COOLDOWN 1000

//Millis time for entering soft cooldown
long fault_cooldown_time = 0;

//Current state of the fault system
#define FAULT_CLEAR 0
#define FAULT_TIME 1
#define FAULT_SOFT_TRIP 2
#define FAULT_HARD_TRIP 3
byte fault_state = FAULT_SOFT_TRIP;


void setup() {
  debug.begin(DEBUG_BAUD);
  debug.println("&Start;");
  initCurrent();
  initVoltage();
  initLED();
  initPower();
}

bool manualControl = false;

void loop() {
  //Poll current and voltage so the filters are kept fresh
  getVoltage();
  getCurrent();

  //Process serial interface
  if(debug.available() > 0){
    if(manualControl){
      processManualControl();
    }else{
      if(debug.read() == 'm'){
        manualControl = true;
        debug.println("&Entering manual control;");
      }
    }
  }

  //If in hard trip state, which can only be cleared by reset
  if (fault_state == FAULT_HARD_TRIP) {
    //Blink error message
    showLED(1, 1, 0);
    delay(500);
    showLED(1, 0, 0);
    delay(500);
    debug.println("&Reset to clear trip;");
    return; //Don't continue to loop, there's nothing to do
  }
  bool currentTrip = getCurrent() > FAULT_MAX_CURRENT;
  bool overVoltageTrip = getVoltage() > FAULT_MAX_VOLTAGE;
  bool underVoltageTrip = getVoltage() < FAULT_MIN_VOLTAGE;

  //If any of the indicators is tripped
  if (currentTrip || overVoltageTrip || underVoltageTrip) {
    if (fault_state == FAULT_CLEAR) {
      //If no existing fault, enter the pre-fault stage
      fault_state = FAULT_TIME;
      fault_start_time = millis();
    } else if (fault_state == FAULT_TIME && millis() > fault_start_time + FAULT_TIME_THRESHOLD) {
      //If in pre-fault, shut off load and go to error state.
      //Choose which trip state to go to.
      if (underVoltageTrip) {
        debug.println("&Entering hard trip;");
        //Load will stay permanently off, till hard reset.
        fault_state = FAULT_HARD_TRIP;
      } else { //It's over voltage or over current.
        //Try checking the load later.
        debug.println("&Entering soft trip;");
        fault_state = FAULT_SOFT_TRIP;
        showLED(0, 0, 1);
        fault_cooldown_time = millis();
      }
      disconnectPower();
    }
  } else { //No faults.
    if (fault_state == FAULT_TIME || (fault_state == FAULT_SOFT_TRIP && millis() > fault_cooldown_time + FAULT_SOFT_TRIP_COOLDOWN)) {
      debug.println("&\t\t Clear trip;");
      fault_state = FAULT_CLEAR;
      connectPower();
    }
    if (fault_state == FAULT_CLEAR) {
      //Show green LED
      showLED(0, 1, 0);
    }
  }
}

void processManualControl(){
  char cmd = debug.read();
  if(cmd == 'x'){
    manualControl = false;
    debug.println("&Exit manual;");
  }else if(cmd == 'r'){
    fault_state = FAULT_CLEAR;
  }else if(cmd == 'd'){
    printDebug();
  }else if(cmd == 'o'){
    connectPower();
    debug.println("&Load on;");
  }else if(cmd == 'l'){
    disconnectPower();
    debug.println("&Load off;");
  }
}

void printDebug() {
  float i = getCurrent();
  float v = getVoltage();
  debug.print("$");
  debug.print(powerState);
  debug.print(" ");
  debug.print(i);
  debug.print(" ");
  debug.print(v);
  debug.print(" ");
  printFaultState();
  debug.println(";");
}
/**
 * Convert the fault state to a human readable string and send it to the debug port.
 */
void printFaultState(){
  switch(fault_state){
    case FAULT_CLEAR:
      debug.print("c");
      break;
    case FAULT_TIME:
      debug.print("t");
      break;
    case FAULT_SOFT_TRIP:
      debug.print("s");
      break;
    case FAULT_HARD_TRIP:
      debug.print("h");
      break;
    default:
      debug.print("u");
      break;
  }
}


/**
   Initializes cutoff relay pin and leaves the relay in an open state.
*/
void initPower() {
  pinMode(CUTOFF_PIN, OUTPUT);
  digitalWrite(CUTOFF_PIN, CUTOFF_ENABLE);
}


/**
 * Control of the power cutoff
 */

void connectPower() {
  if (!powerState) {
    digitalWrite(CUTOFF_PIN, CUTOFF_DISABLE);
    powerState = true;
  }
}

void disconnectPower() {
  if (powerState) {
    digitalWrite(CUTOFF_PIN, CUTOFF_ENABLE);
    powerState = false;
  }
}
/**
   Initializes current sensor.
   First, it enables the 3.3V regulator, then it
   sets sense pin to output and calibrates offset.
*/
void initCurrent() {
  //Turn on the 3.3v regulator
  pinMode(SUPPLY_3V3_ENABLE_PIN, OUTPUT);
  digitalWrite(SUPPLY_3V3_ENABLE_PIN, SUPPLY_3V3_ON);
  //Give it 50ms to stablilize
  delay(50);
  //Setup the ADC pin
  pinMode(CURRENT_ADC_PIN, INPUT);
  int offset_calibration = 0;
  //Collect 5 ADC samples
  for (int i = 0; i < 5; i++) {
    offset_calibration += analogRead(CURRENT_ADC_PIN);
    //debug.println(analogRead(CURRENT_ADC_PIN));
    delay(5);
  }
  //Average them and save the value
  current_offset = offset_calibration / 5;
  debug.print("&Current offset: ");
  debug.print(current_offset);
  debug.println(";");
}

/**
   Reads the ADC and returns the current measurement in Amps.
*/
float getCurrent() {
  //Get the raw ADC sample
  int sample = analogRead(CURRENT_ADC_PIN);
  //Filter it
  sample = currentFilter(sample);
  //Convert and return
  //Convert sample to voltage
  float current = sample / 1024.0 * 5.0;
  //Remove offset
  current = current - 1.65;
  //Divide by mv/Amp, to get amps.
  current = current / -0.132;
  return current;
}

float current_running_filter = 0;
int currentFilter(int sample) {
  if (current_running_filter == 0) {
    current_running_filter = sample;
  } else {
    current_running_filter += CURRENT_FILTER_STRENGTH * (sample - current_running_filter);
  }
  return (int) current_running_filter;
}

/**
   Initializes the voltage sensor pin
*/
void initVoltage() {
  analogReference(DEFAULT);
  pinMode(VOLTAGE_ADC_PIN, INPUT);
}

/**
   Reads the ADC and returns the voltage measurement in Volts.
*/
float getVoltage() {
  int sample = analogRead(VOLTAGE_ADC_PIN);
  sample = voltageFilter(sample);
  return (float) sample / 1024.0 * VOLTAGE_ADC_RANGE;
}

float voltage_running_filter = 0;
int voltageFilter(int sample) {
  if (voltage_running_filter == 0) {
    voltage_running_filter = sample;
  } else {
    voltage_running_filter += VOLTAGE_FILTER_STRENGTH * (sample - voltage_running_filter);
  }
  return (int) voltage_running_filter;
}
/**
   Initializes the LED pins and blinks the startup sequence.
*/
void initLED() {
  pinMode(LED_R, OUTPUT);
  pinMode(LED_G, OUTPUT);
  pinMode(LED_B, OUTPUT);
  showLED(1, 0, 0);
  delay(250);
  showLED(0, 1, 0);
  delay(250);
  showLED(0, 0, 1);
  delay(250);
  showLED(1, 1, 1);
  delay(250);
  showLED(0, 0, 0);
}

/**
   Sets the LED on/off status. Values are either 1 (HIGH), or 0 (LOW)
*/
void showLED(byte r, byte g, byte b) {
  digitalWrite(LED_R, r);
  digitalWrite(LED_G, g);
  digitalWrite(LED_B, b);
}

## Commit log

2021-03-29 Second initial commit
    [Phase I - BOM.xlsx]
2021-03-29 Update code to enable machine readability
    Also removed some unnecessary debug printouts.
2021-03-29 Add and reorganize the hardware files.
    Received permission to upload the KiCAD footprints with the project, so added the project source files.
    [Bill of Materials.xlsx, EGR216 Honors Contract Board.kicad_pcb, EGR216 Honors Contract Board.sch]
2021-09-24 Add schematic image
